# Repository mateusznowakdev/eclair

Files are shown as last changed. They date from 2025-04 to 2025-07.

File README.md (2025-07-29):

# EclairM0

[Project description](https://mateusznowak.dev/eclair) and [build instructions](https://mateusznowak.dev/eclair/build) can be found on my website.

Hardware files can be previewed in these third-party web applications:

- KiCad files (board) -- https://kicanvas.org
- OpenSCAD files (enclosure) -- https://openscad.cloud/openscad/

License terms for software and hardware are present in the [LICENSE.md](./LICENSE.md) file.

Jump to:

- [building firmware from source](#building-firmware-from-source)
- [updating font data](#updating-font-data)
- [3D-printing the enclosure](#3d-printing-the-enclosure)
- [engraving button labels](#engraving-button-labels)
- [changelog](#changelog)

---

## Building firmware from source

Install the TinyGo SDK. Copy EclairM0 board definition files as follows:

| File from this repo | Target SDK directory |
|---|---|
| firmware/_board/board_eclair-m0.go | src/machine |
| firmware/_board/eclair-m0.json | targets |
| firmware/_board/eclair-m0.ld | targets |

Now you should be able to build and upload new firmware, like this:

```bash
cd firmware
tinygo flash -target eclair-m0 -size short
```

## Updating sprite data

Raw pixel data is stored in PGM (portable graymap) files, editable with GIMP. Spritesheet images must be 8px or 16px tall. The background is white, the foreground is black, and the mask information is gray/black (used when rendering sprites on top of each other).

Source files can be converted into a working Go code, using the `tools/make_spritesheet_data.py` script, which should work with any modern version of Python:

```bash
cd tools
python3 make_spritesheet_data.py path/to/file.pgm path/to/file.txt
```

## 3D-printing the enclosure

Creality Ender-3 V3 KE is my 3D printer. I'm using OrcaSlicer 2.2.0, and at this point I'm too scared to update :)

These are the printing settings recommended by me:

- Global filament settings (PLA) &rarr; 215&deg;C nozzle, 60&deg;C bed
- "0.12mm Fine" base preset
- Quality &rarr; Seam position: BACK
- Quality &rarr; Scarf joint seam: CONTOUR
- Quality &rarr; Elephant foot compensation: 0.15mm (depends on the printer calibration, default is 0.05mm)
- Quality &rarr; Precise wall: ON
- Quality &rarr; Walls printing order: INNER/OUTER
- Quality &rarr; Detect overhang walls: OFF
- Strength &rarr; Bottom surface pattern: ARCHIMEDEAN or HILBERT for best appearance
- Speed &rarr; First layer: 20mm/s (default is 50mm/s and it's too fast)
- Speed &rarr; Top surface: 100mm/s (default is 250mm/s)

Supports should not be necessary for the bridge under the slide switch cutout.

Any bright filament (yellow, white) would hide most of the inaccuracies, and it will also make the engraved letters more visible.

## Engraving button labels

Gerber files generated by KiCad can be converted to a G-code compatible with many desktop CNCs. If you happen to use `pcb2gcode`, the example config is available in the repo.

It's difficult to get it right the first try, because:

- the router table is never perfectly flat
- the enclosure is thin and can bend a little
- auto-generated toolpaths may result in thicker cuts for some letters
- some PLA types melt too soon

The best idea is to set the spindle so it barely touches the enclosure at the highest point. Start cutting all letters at once, and lower the spindle at 0.1mm increments. If any letter pair looks okay (at about 0.3mm deep), remove it from the job file and repeat.

## Changelog

### Software

Version 1.3:

- Added two more slots for notes, for a total of 5
- Changed the user interface in all apps

Version 1.2:

- Added two more slots for notes

Version 1.1:

- Added Shift key, and the menu for inserting symbols and some keyboard keys
- Changed font to NewStroke
- Changed USB VID/PID and manufacturer/device name
- Changed battery voltage measurement code 
  - **Replace resistors before updating -- see Rev.D changelog below**

Version 1.0:

- Initial version

### Hardware

Rev.D:

- Switched to LIR2025(H) battery
- Changed R51 and R52 resistors, to 22K and 5.1K respectively, to have 1V max output

Rev.C:

- Added ADC/DAC test point, and extra soldering pad for attaching the unmodified Li-Po battery

Rev.B:

- Added Schottky diode to prevent battery from back-powering the USB host
- Added 5V, 3.3V and extra GND test points

Rev.A:

- Initial revision

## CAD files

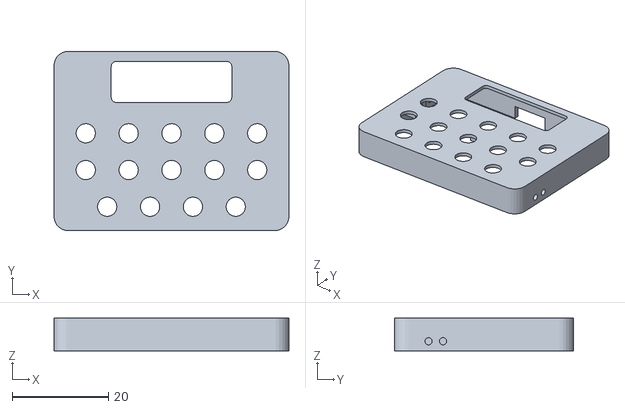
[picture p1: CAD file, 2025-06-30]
hardware/enclosure/top.stl
48.8 x 37.2 x 6.80

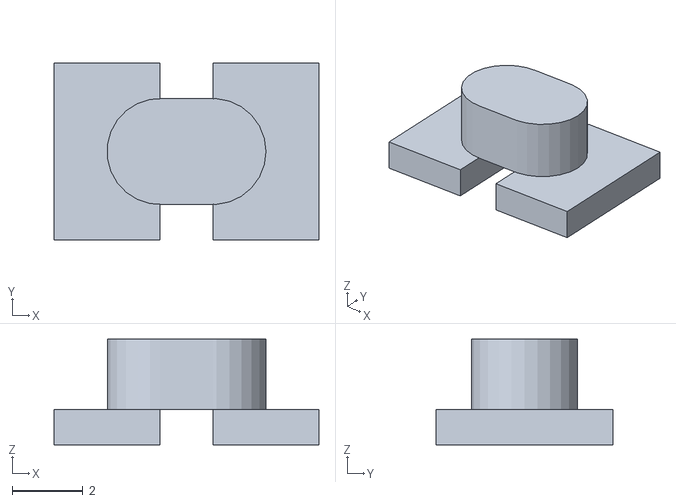
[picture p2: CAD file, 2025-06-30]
hardware/enclosure/slide.stl
7.50 x 5.00 x 3.00

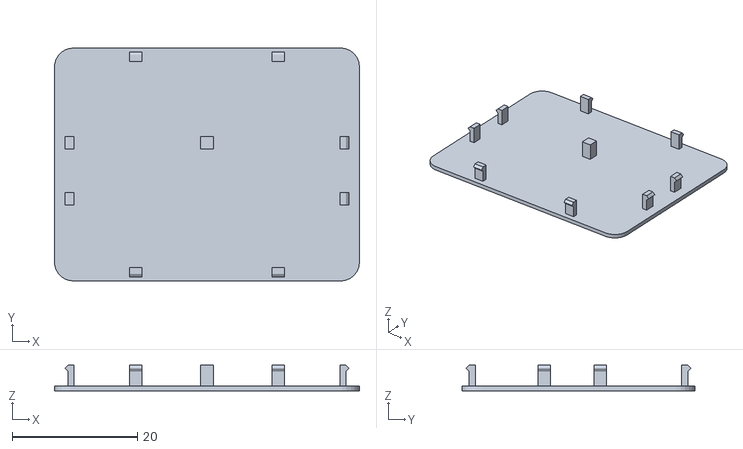
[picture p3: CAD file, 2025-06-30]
hardware/enclosure/bottom.stl
48.8 x 37.2 x 4.10

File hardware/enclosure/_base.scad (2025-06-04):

module rsquare(dim, r=0, center=false) {
  x = dim[0];
  y = dim[1];

  ox = center ? -x/2 : 0;
  oy = center ? -y/2 : 0;

  translate([ox, oy]) {
    union() {
      translate([r, 0])
        square([x-2*r, y]);
      translate([0, r])
        square([x, y-2*r]);
      translate([r, r])
        circle(r);
      translate([x-r, r])
        circle(r);
      translate([r, y-r])
        circle(r);
      translate([x-r, y-r])
        circle(r);
    }
  }
}

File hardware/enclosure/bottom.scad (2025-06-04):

use<_base.scad>

$fn = 25;

// board dimensions
bx = 44.45;
by = 34.93;

// wall thickness
wlr = 2.0; // left-right
wtb = 1.0; // top-bottom
wfr = 0.8; // front-rear

// tolerance
tol = 0.15;

module Base() {
  translate([0, 0, -wfr])
    linear_extrude(wfr)
      rsquare([bx+2*wlr+2*tol, by+2*wtb+2*tol], r=3, center=true);
}

module Snaps() {
  sx = 2;
  sy = 1;
  sz = 3.3;

  snaps = [
    [[-11.4,  by/2], 90],
    [[ 11.4,  by/2], 90],
    [[ bx/2,   3.5], 0],
    [[ bx/2,  -5.5], 0],
    [[ 11.4, -by/2], 270],
    [[-11.4, -by/2], 270],
    [[-bx/2,  -5.5], 180],
    [[-bx/2,   3.5], 180],
    // these two are joined to form a single solid support
    [[    0,   3.5], 0],
    [[    0,   3.5], 180],
  ];

  for (s = snaps)
    translate(s[0])
      rotate([0, 0, s[1]])
        // single snap
        translate([0, sx/2])
          rotate([90, 0, 0])
            linear_extrude(sx)
              polygon([[0, 0], [-sy, 0], [-sy, sz], [0, sz], [0.5, sz-0.5], [0, sz-1.0]]);
}

Base();
Snaps();

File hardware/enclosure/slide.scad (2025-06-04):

use<_base.scad>

$fn = 25;

// switch dimensions
sx = 4.5;
sy = 3;
travel = 1.5;

// wall thickness
wlr = 2.0; // left-right

module Top() {
  linear_extrude(wlr)
    rsquare([sx, sy], r=sy/2, center=true);
}

module Bottom() {
  translate([0, 0, -wlr/2])
    linear_extrude(wlr/2+0.001) // prevent rendering issues
      difference() {
        square([sx+travel+1.5, sy+2], center=true);
        square([1.5, sy+2], center=true);
      }
}

Top();
Bottom();

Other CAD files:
hardware/enclosure/top.scad

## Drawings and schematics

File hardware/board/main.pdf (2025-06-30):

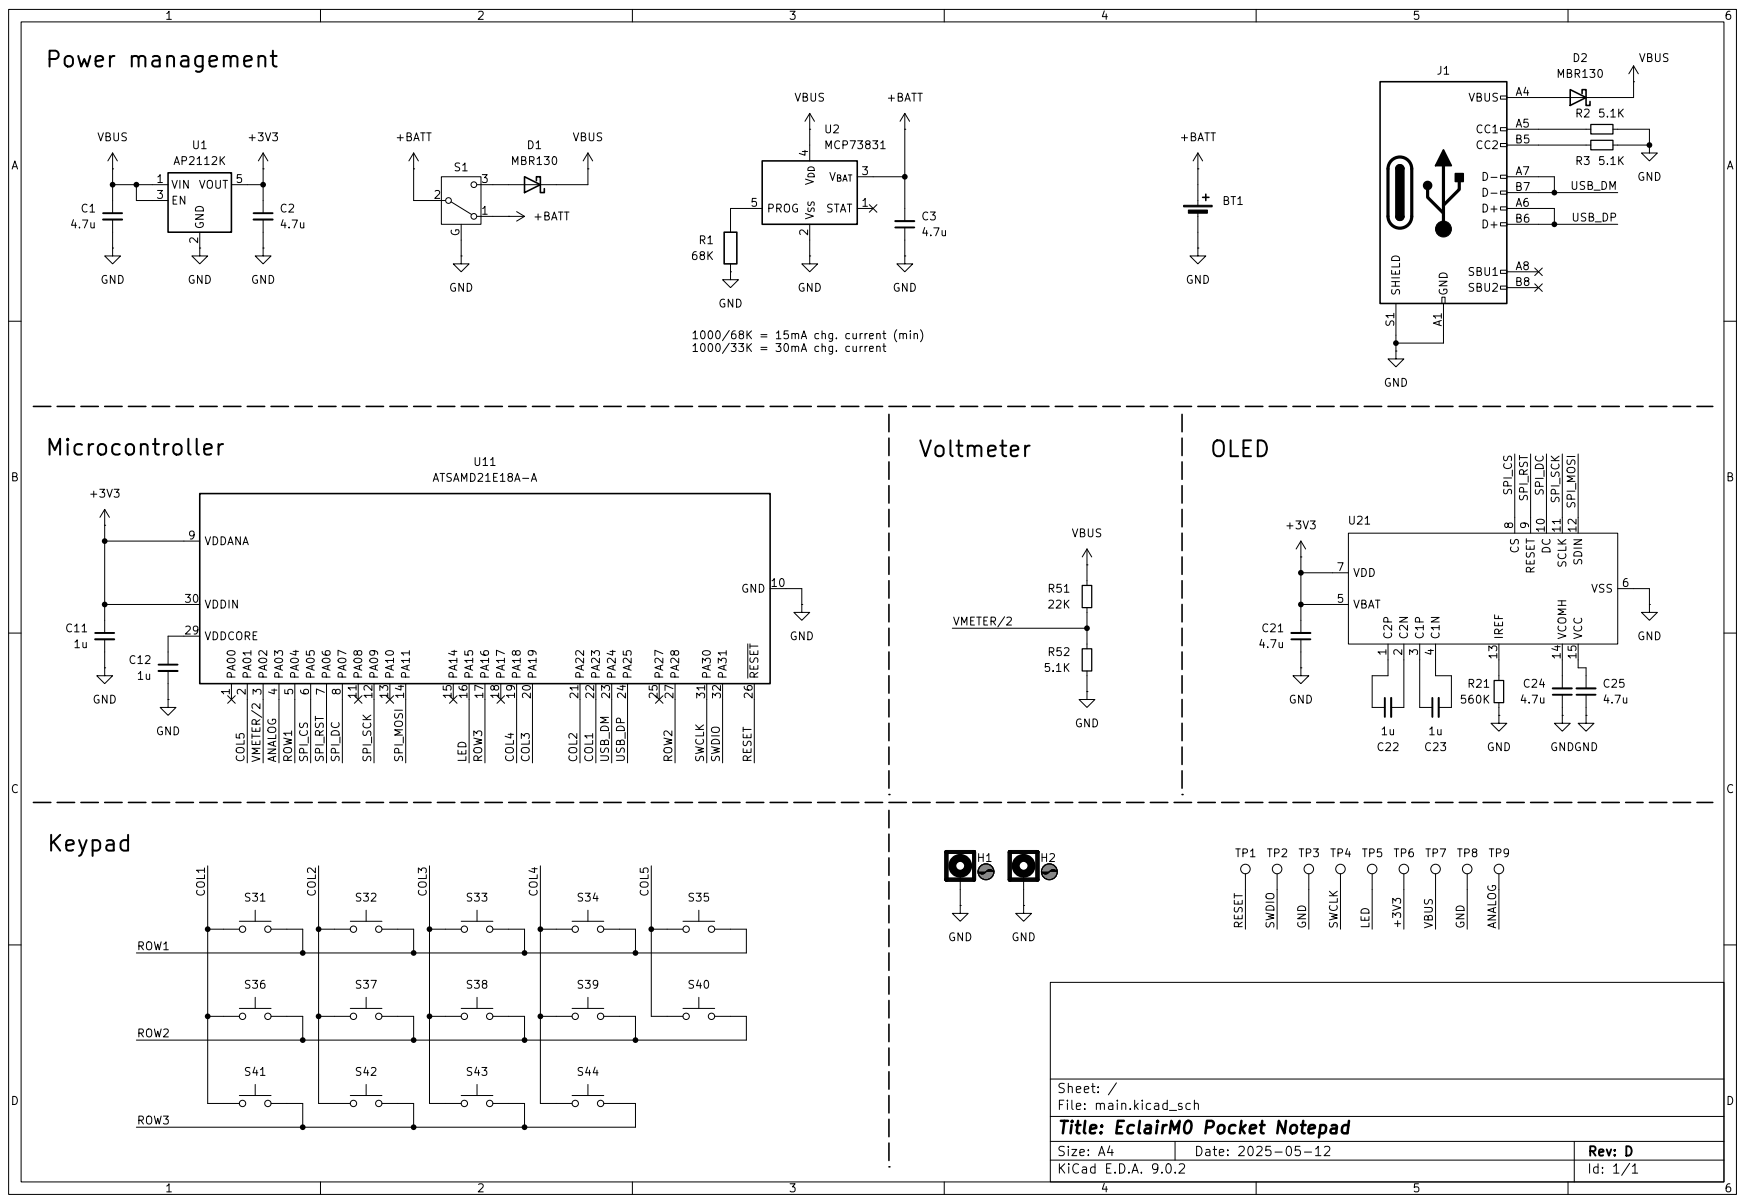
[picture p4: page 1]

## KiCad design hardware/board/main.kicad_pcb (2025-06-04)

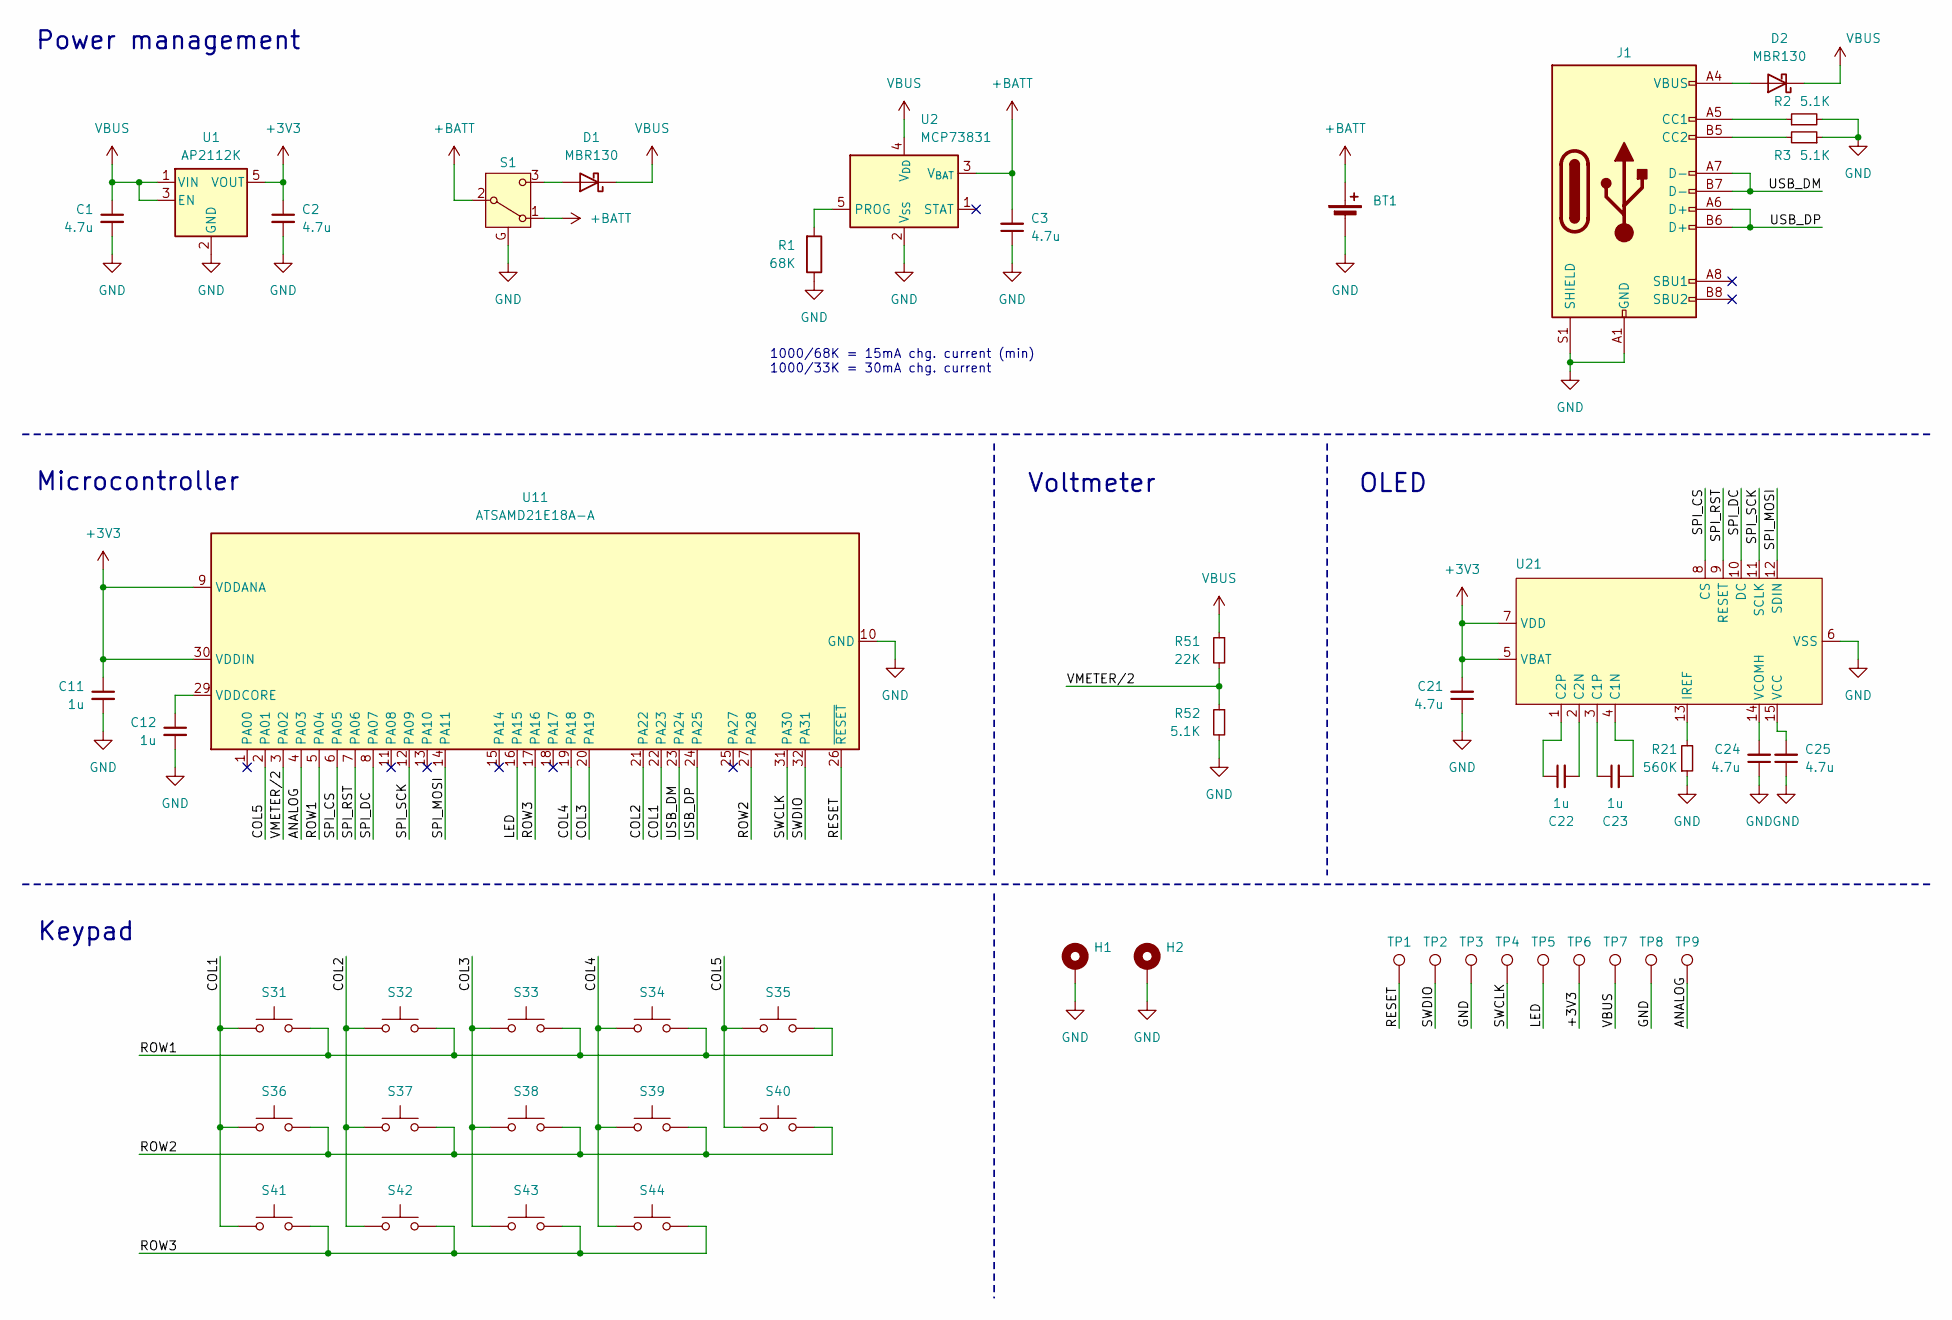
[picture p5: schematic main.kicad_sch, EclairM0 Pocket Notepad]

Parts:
BT1: BatteryHolder_MPD_BC2003_1x2032
C1, C2, C3, C21, C24, C25: 4.7u; C_0805_2012Metric
C11, C12, C22, C23: 1u; C_0805_2012Metric
D1, D2: MBR130; D_1206_3216Metric
H1, H2: MountingHole_2.2mm_M2_Pad_Small
J1: USB_C_Receptacle_GCT_USB4105-xx-A_16P_TopMnt_Horizontal
R1: 68K; R_0805_2012Metric
R2, R3, R52: 5.1K; R_0805_2012Metric
R21: 560K; R_0805_2012Metric
R51: 22K; R_0805_2012Metric
S1: SW_SPDT; SW_SPDT_PCM12
S31, S32, S33, S34, S35, S36, S37, S38, S39, S40, S41, S42, S43, S44: SW_SPST_EVQQ2
TP1, TP2, TP3, TP4, TP5, TP6, TP7, TP8, TP9: TestPoint_Pad_D1.0mm
U1: AP2112K; SOT-23-5
U2: MCP73831; SOT-23-5
U11: ATSAMD21E18A-A; TQFP-32_7x7mm_P0.8mm
U21: REX012832

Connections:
+3V3: C2.1, C11.1, C21.2, TP6.1, U1.5 (VOUT), U11.9 (VDDANA), U11.30 (VDDIN), U21.5 (VBAT), U21.7 (VDD)
+BATT: BT1.1 (+), C3.2, S1.1 (A), S1.2 (B), U2.3 (V_{BAT})
/ANALOG: TP9.1, U11.4 (PA03)
/COL1: S31.1, S36.1, S41.1, U11.22 (PA23)
/COL2: S32.1, S37.1, S42.1, U11.21 (PA22)
/COL3: S33.1, S38.1, S43.1, U11.20 (PA19)
/COL4: S34.1, S39.1, S44.1, U11.19 (PA18)
/COL5: S35.1, S40.1, U11.2 (PA01)
/LED: TP5.1, U11.16 (PA15)
/RESET: TP1.1, U11.26 (~RESET)
/ROW1: S31.2, S32.2, S33.2, S34.2, S35.2, U11.5 (PA04)
/ROW2: S36.2, S37.2, S38.2, S39.2, S40.2, U11.27 (PA28)
/ROW3: S41.2, S42.2, S43.2, S44.2, U11.17 (PA16)
/SPI_CS: U11.6 (PA05), U21.8 (CS)
/SPI_DC: U11.8 (PA07), U21.10 (DC)
/SPI_MOSI: U11.14 (PA11), U21.12 (SDIN)
/SPI_RST: U11.7 (PA06), U21.9 (RESET)
/SPI_SCK: U11.12 (PA09), U21.11 (SCLK)
/SWCLK: TP4.1, U11.31 (PA30)
/SWDIO: TP2.1, U11.32 (PA31)
/USB_DM: J1.A7 (D-), J1.B7 (D-), U11.23 (PA24)
/USB_DP: J1.A6 (D+), J1.B6 (D+), U11.24 (PA25)
/VMETER/2: R51.2, R52.1, U11.3 (PA02)
GND: BT1.2 (-), C1.2, C2.2, C3.1, C11.2, C12.2, C21.1, C24.1, C25.1, H1.1, H2.1, J1.A1 (GND), J1.A12 (GND), J1.B1 (GND), J1.B12 (GND), J1.S1 (SHIELD), R1.1, R2.2, R3.1, R21.1, R52.2, S1.G, TP3.1, TP8.1, U1.2 (GND), U2.2 (V_{SS}), U11.10 (GND), U11.28 (GND), U21.6 (VSS)
unnamed: D1.2 (A), S1.3 (C)
unnamed: D2.2 (A), J1.A4 (VBUS), J1.A9 (VBUS), J1.B4 (VBUS), J1.B9 (VBUS)
unnamed: J1.A5 (CC1), R2.1
unnamed: J1.B5 (CC2), R3.2
unnamed: R1.2, U2.5 (PROG)
unnamed: C12.1, U11.29 (VDDCORE)
unnamed: C23.2, U21.4 (C1N)
unnamed: C23.1, U21.3 (C1P)
unnamed: C22.2, U21.2 (C2N)
unnamed: C22.1, U21.1 (C2P)
unnamed: R21.2, U21.13 (IREF)
unnamed: C25.2, U21.15 (VCC)
unnamed: C24.2, U21.14 (VCOMH)
VBUS: C1.1, D1.1 (K), D2.1 (K), R51.1, TP7.1, U1.1 (VIN), U1.3 (EN), U2.4 (V_{DD})

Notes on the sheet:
Microcontroller
Voltmeter
OLED
1000/68K = 15mA chg. current (min) 1000/33K = 30mA chg. current
Keypad
Power management

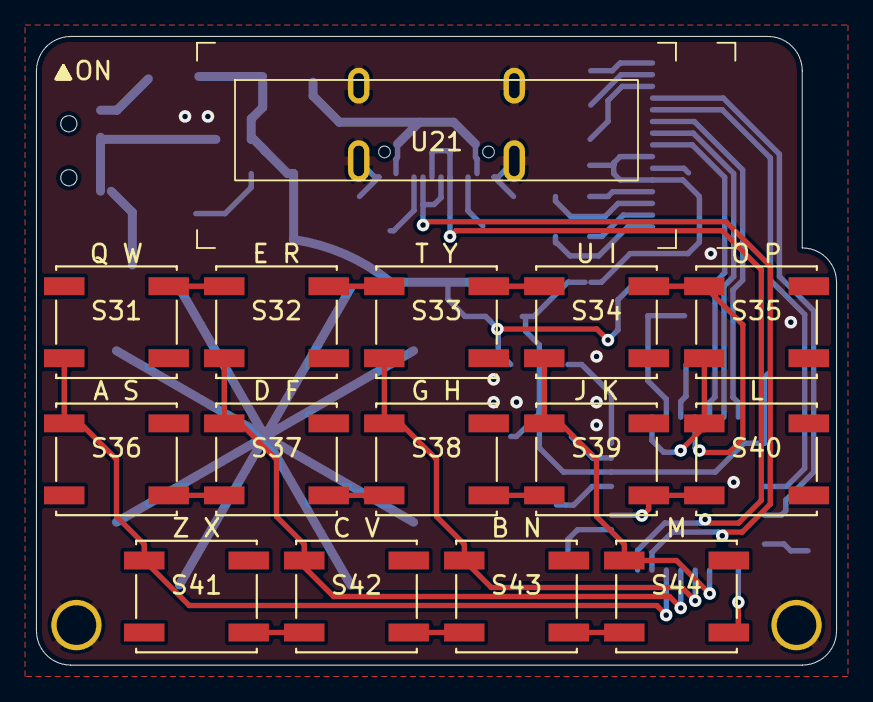
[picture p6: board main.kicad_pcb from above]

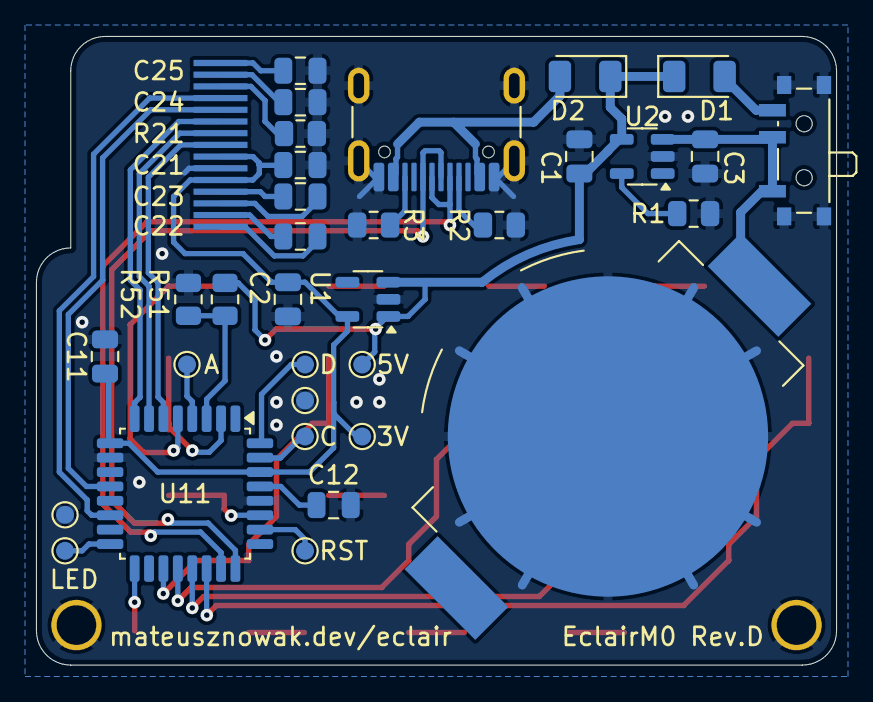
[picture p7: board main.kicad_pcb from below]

Board: 4 copper layers, 44.5 x 34.9 mm, 50 parts (33 on the bottom side), 38 nets.

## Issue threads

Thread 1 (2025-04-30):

Rechargeable Button Cell(s)?

LinuxinaBit, 2025-04-30:
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

This is a really cool project ❤

I was looking through your [overview](https://mateusznowak.dev/projects/eclair-pocket-notepad/) and saw the hard-to-source and sketchy-looking battery setup which gives me a little pause when considering building it.

Did you know they make rechargeable button cell batteries?
https://en.wikipedia.org/wiki/Button_cell#Rechargeable_variants

They would hold less charge, sure, but it could be a much more user-friendly approach to the whole battery situation (assuming the microcontroller is efficient enough) and they’d be easily replaceable too, assuming you added the right holder.

It would probably require some tinkering to get them recharging *in* the device, but it shouldn’t be that bad seeing as there are USB-based chargers available for really cheap…
You could even (theoretically) add a small solar cell somewhere, though that’s probably not something you’re looking to add :)

Have a good one 👋

mix127, 2025-05-01:
https://hackaday.io/project/159139-tiny-solar-energy-module-tsem
This power is very small. In my opinion critical is more RAM&ROM, more power or increase of working time. For example 16 days. People need small computer/handheld / pda etc. But RAM and power is important.

mateusznowakdev, 2025-05-02:
Hi,

thanks for your feedback.

To be fair, I've never really considered using these. I always thought rechargeable coin cells are 3.0V nominal just like regular ones, which would require me to make some significant changes - modify the bootloader, make sure the flash cycles are set up correctly to prevent data loss, or maybe use buck-boost converter instead of LDO. I've tried using CR2032s already and run into a lot of problems.

Based on my quick research (it's 4-day weekend here so I'm busy with other stuff), LIR2032s can be charged with the MCP73831 (https://hackaday.io/project/29506-lir2032-coin-cell-charger), so the required circuitry is already here. I would have to slightly rearrange components on the bottom of PCB, but it seems doable.

However, it may be difficult to fit 2032 because the battery holder adds some extra thickness and the entire thing won't fit in the existing enclosure, but I wonder if 2025 would work. If there are lower-profile battery holders available, of course. I'm also curious how thick actually are these batteries with pre-welded terminals, they are through-hole but you could trim the leads and solder these _onto_ the PCB.

I don't think the power consumption would be a problem here, there are no power-hungry components such as wireless communication.

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

For now, I don't plan on adding any solar panels :)

I'm keeping this issue open, and maybe I'll post some updates later this month.

mateusznowakdev, 2025-05-23:
Quick update: I've ordered few LIR2025**H** batteries and did some testing.

Example datasheet: https://www.micros.com.pl/mediaserver/info-ak%20lir2025h-1x1.pdf

These really are 40mAh, no scam. Tested with Seeed XIAO doing nothing at 48MHz, ~11mA discharge current, resulted in ~3h runtime. Very cool. I guess with the reduced power consumption, it would be 6-8h on a single charge - to be confirmed.
The battery can be charged with both 15mA and 30mA charging current, so the regular LIR2025 batteries should be compatible.

I am working on an updated PCB this weekend, then I will order one, and upload new files once I confirm that everything works fine.

Closed 2025-06-04.

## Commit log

2025-04-05 Prepare files for public release
    [_base.scad, bottom.scad, main.kicad_pcb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]
2025-04-08 Update board files
    Added extra pad, so the battery can be connected without removing the protection circuit
    [main.kicad_pcb, main.kicad_sch]
2025-04-19 Update enclosure files
    Fix misaligned display hole, slightly change lid snaps' positions
    [bottom.scad, top.scad]
2025-04-23 Update battery footprint
    Remove solder paste from battery pads
    [main.kicad_pcb]
2025-04-23 Update project name to improve discoverability
    [main.kicad_pcb, main.kicad_sch]
2025-06-04 Change battery measurement circuit
    Use 22K / 5.1K voltage divider and fixed 1V reference. This should work correctly even if system voltage goes below 3.3V.
    [main.kicad_pcb, main.kicad_sch]
2025-06-04 Add custom TinyGo board definition
    Do not use Trinket M0 as a base anymore. This allows me to set custom USB VID/PID and default pins.
2025-06-04 Add custom board definition to CI pipeline
2025-06-04 Replace Li-Po battery with rechargeable coin battery
    Charging circuit has been moved closer to the USB. The slide switch is now mounted on the bottom layer. Battery protection circuit is removed due to lack of space. Updated for KiCad 9.0.2, optimized traces, run ERC/DRC.
    [main.kicad_pcb, main.kicad_sch]
2025-06-04 Update font data
    Use modified version of NewStroke which is KiCad font used to engrave enclosure's labels. Add missing glyphs to get full ASCII support. Generate glyph data from PBM image, remove old HTML editor.
2025-06-04 Change how current launcher entry is highlighted
2025-06-04 Display popup menu for inserting new characters into a note
2025-06-04 Update drivers to version that includes the SSD1306 SPI fix
2025-06-04 Create main enclosure from scratch
    Move origin to the center, update dimensions to match reality even more, simplify math, add comments when necessary, add supports to protect the display
    [top.scad]
2025-06-04 Update slide switch file
    [_base.scad, slide.scad, top.scad]
2025-06-04 Update enclosure lid file
    [bottom.scad, top.scad]
2025-06-04 Replace basic supports with snap joints
    [bottom.scad, top.scad]
2025-06-17 Update TinyGo and drivers
2025-06-22 Create three note slots, by default open the first one
2025-06-30 Make display cutout slightly larger near the top
    [top.scad]
2025-06-30 Export STL files and PCB schematic
    [bottom.stl, slide.stl, top.stl]
2025-07-05 Use icons in the launcher, mapped to first two rows of buttons
2025-07-06 Add separator between navigation buttons and choice buttons in charmap app
